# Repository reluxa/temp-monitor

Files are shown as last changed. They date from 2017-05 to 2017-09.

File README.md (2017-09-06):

# temp-monitor
Wifi based temperature monitor based on ESP8266 NodeMCU V3 and high accuracy MCP9808 I2C sensor module.

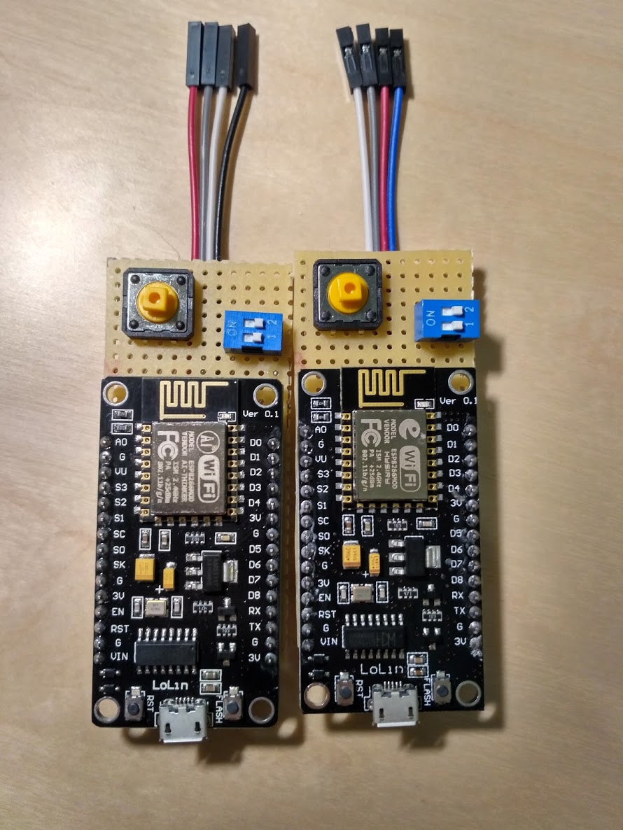
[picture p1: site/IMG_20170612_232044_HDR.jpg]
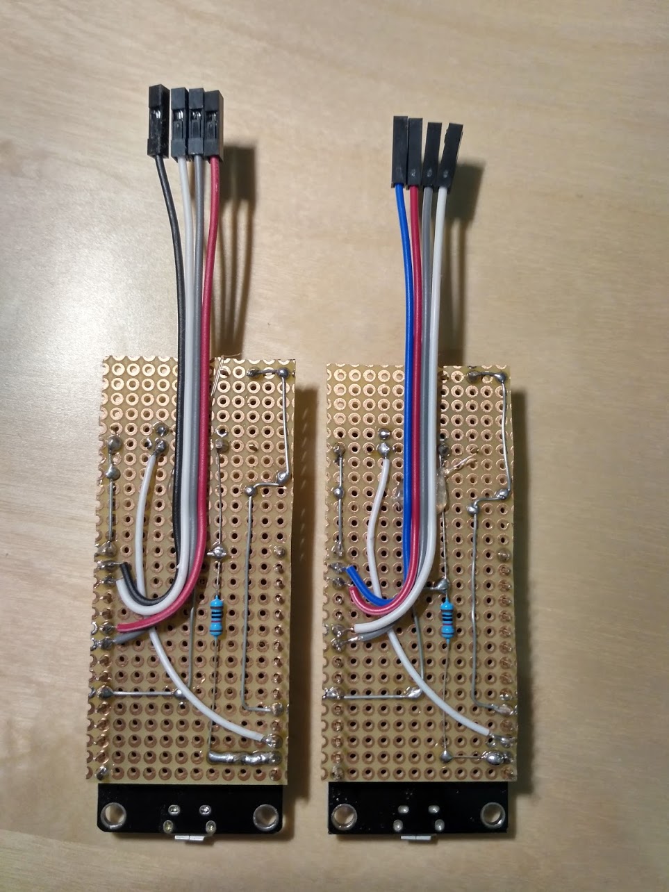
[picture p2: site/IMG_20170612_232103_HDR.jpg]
 

## 3D printed case

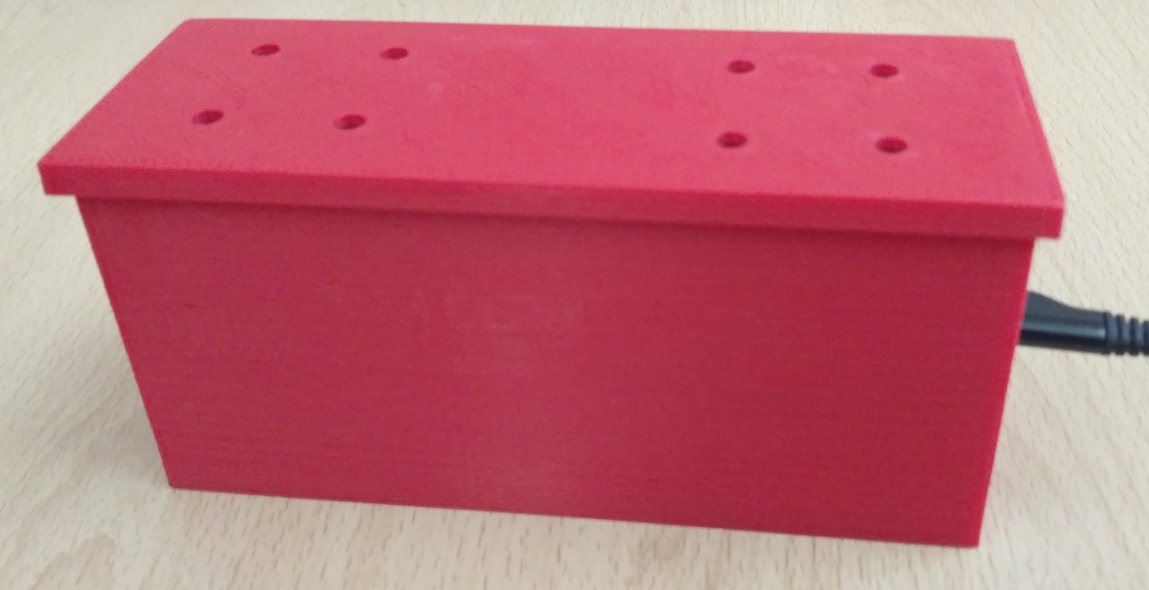
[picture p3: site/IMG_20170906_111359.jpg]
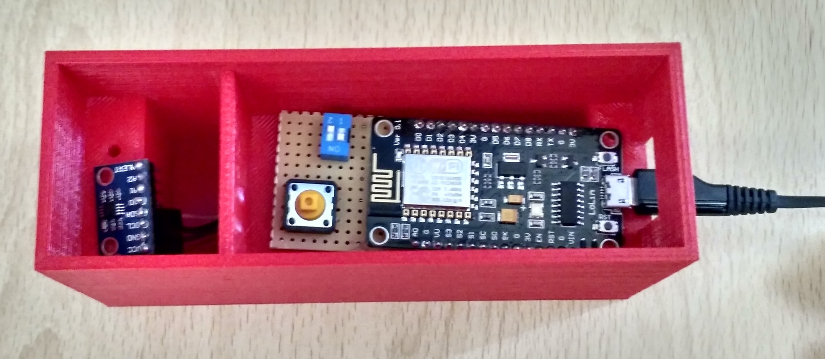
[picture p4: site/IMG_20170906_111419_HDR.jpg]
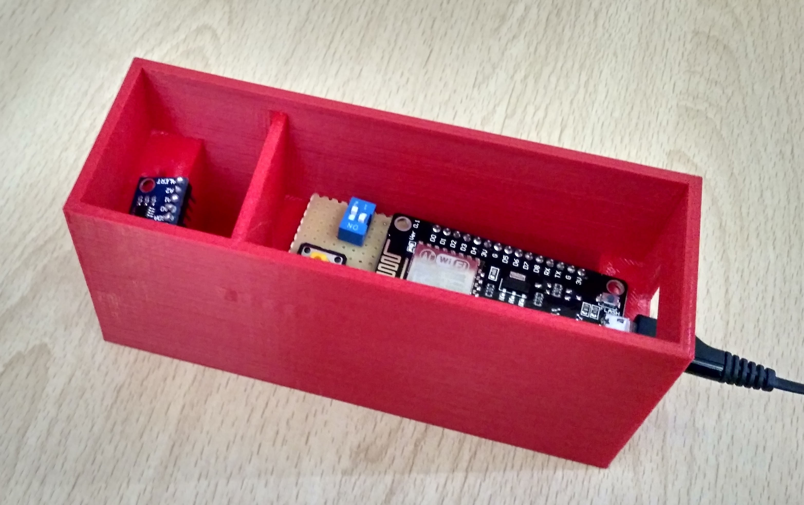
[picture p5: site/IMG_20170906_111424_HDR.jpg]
  

## Features

* The MCP9808 has been selected as the chip accuracy is around 0.25 ℃ in room temp rang. This is much better compared to the other more popular (but also cheaper) sensors (DHT11, DHT22, DS1820B) as they usually have 1 ℃ accuracy without calibration according to their datasheets.
* Uses WIFI manager (https://github.com/tzapu/WiFiManager) to set the configuratio parameters
* The configuration portal can be triggered by pushing the tactile switch while the device is booting up
* The configuration json is saved to the internal SPIFFS, so it's preserved while the device is switched off
* The device goes into deep sleep for 60 seconds after it has finished the read cycle, the dip switch is required here because the reset pin must not be connected to the to the D?? pin while the sketches are uploaded from Arduino IDE 
* Integrated with the company captive portal (once it is connected to the WIFI using the PSK then it also need to be authenticated with and LDAP user/password pair on the captive portal)
* The measured sensor values are sent to blynk using the configured blynk key
* The measured sensor values are sent to the configured MQTT topic ( *topicname* and *topicname/esp chip ip* )
* A software based watchdog has been implemented which resets the ESP if it is running for more than 30 seconds (a usual cycle takes 5-7 seconds)

## Future improvement ideas 
* Implement DNS tunneling to send sensor data embedded in DNS requests instead of MQTT so an open quest wifi can be used wihtout any kind of authentication  
* HTTP Based remote update which is triggerd by an MQTT
* Theare are 1-2 faulty sensor reads per day (above 100C or -0.06C, etc...) this should be filtered out and the measuring should be repeated.

# Bill of Materials

Item | Price | Image | Url
-----|-------|-------------|----
ESP8266 NodeMCU V3| US $2.61 || https://goo.gl/DwVFW4
MCP 9808 I2C High accuracy sensor | US $3.33 |  | https://goo.gl/uG1uYr
5 X 7 cm PCB Board | US $0.33 |  | https://goo.gl/f7Y47i
DIP Switch 1P | US $1.20 (10pcs)|  | https://goo.gl/7sHMXX
Push Button | US $1.45 (20pcs)|  | https://goo.gl/8Kr8Ng
Dupont wires | US $0.31 |  | https://goo.gl/uZkXnA 
10K ohm resistor | US $0.95 |  | https://goo.gl/5iU3pM
Power supply | US $2.36 |  | https://goo.gl/fMZzbB
**In total** | **US $12.21** |

# Blynk based mobile app
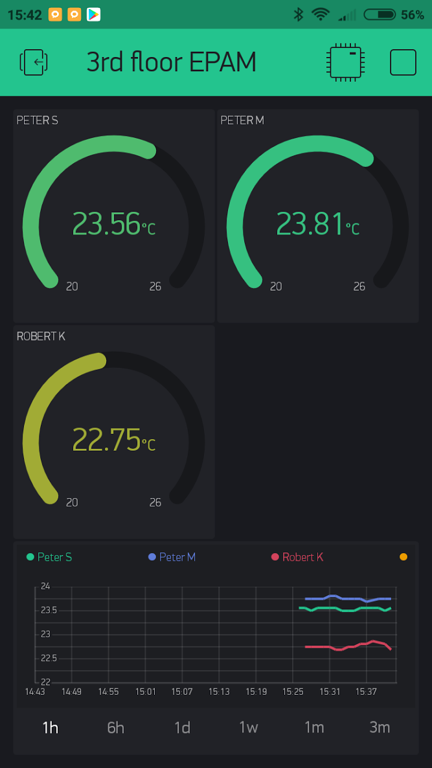
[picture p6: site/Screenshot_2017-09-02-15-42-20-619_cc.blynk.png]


# Live (serverless) heatmap 
https://rawgit.com/reluxa/temp-monitor/master/site/index.html

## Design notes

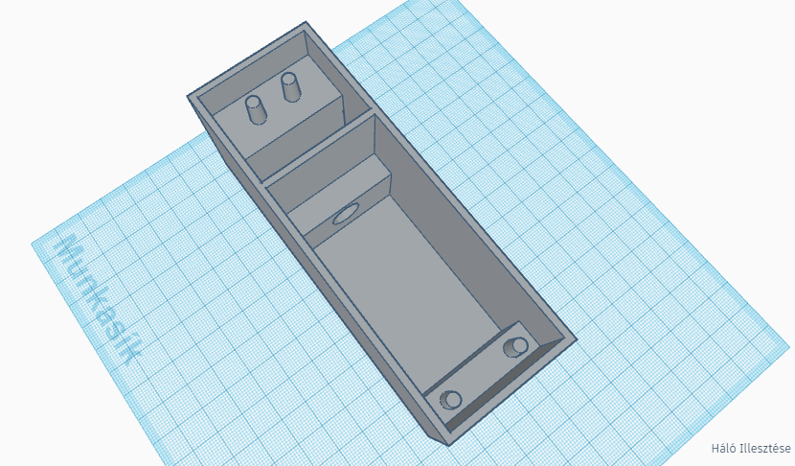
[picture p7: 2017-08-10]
casing/tinkercad/casing_tinkarcad_1.PNG

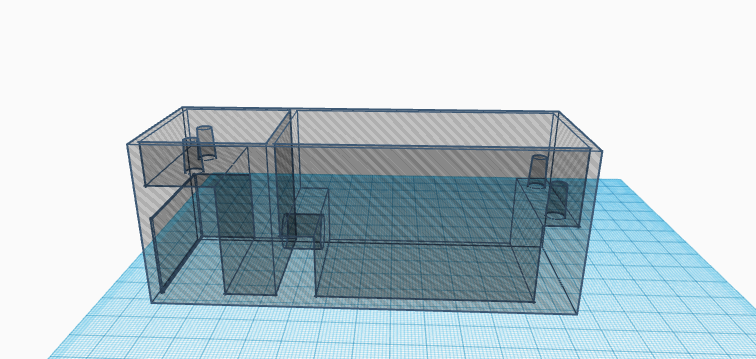
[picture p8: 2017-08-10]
casing/tinkercad/casing_tinkarcad_2.PNG

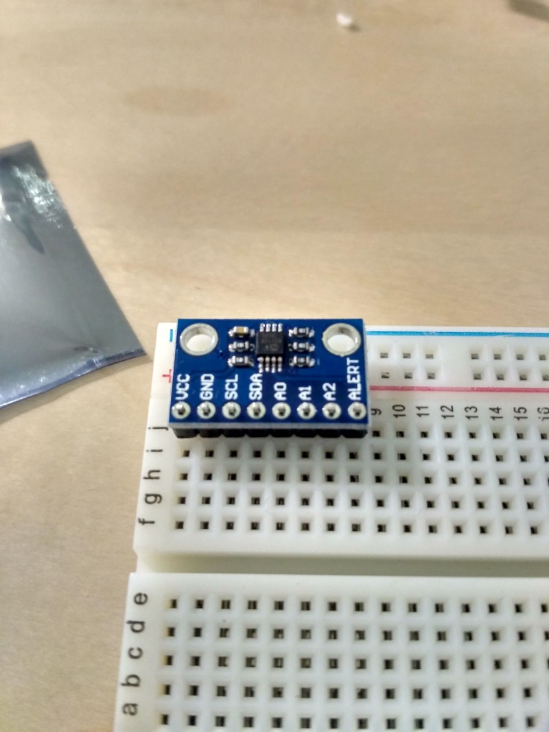
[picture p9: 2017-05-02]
site/IMG_20170501_121737_HDR.jpg

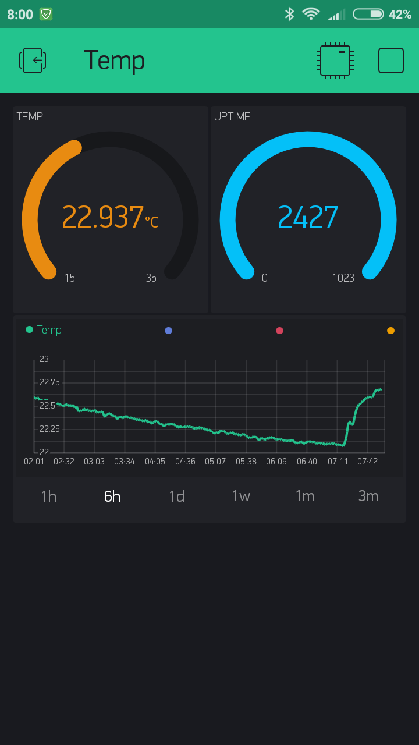
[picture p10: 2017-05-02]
site/Screenshot_2017-05-02-08-00-39-010_cc.blynk.png

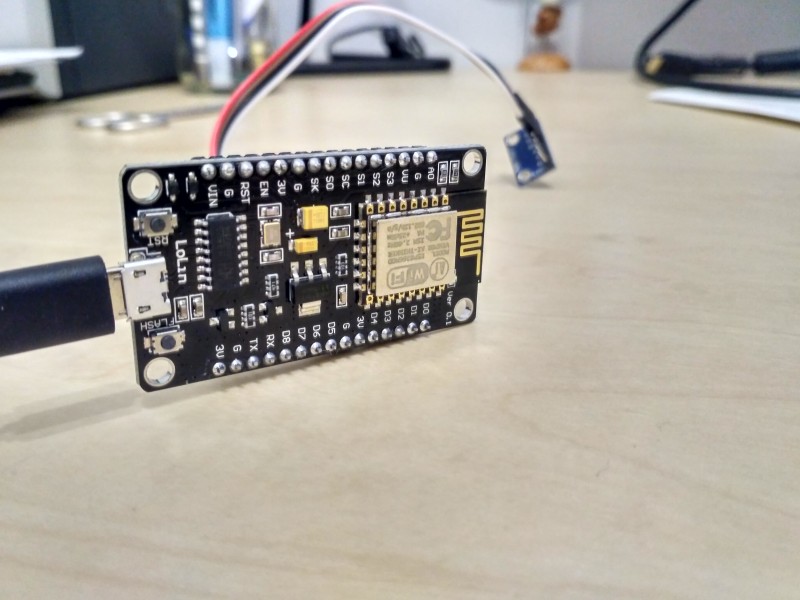
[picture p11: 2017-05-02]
site/IMG_20170502_081327_HDR.jpg

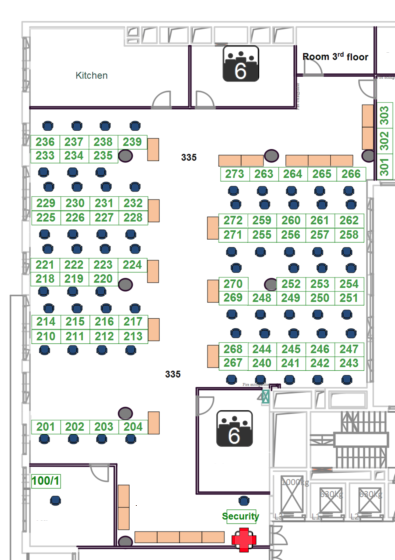
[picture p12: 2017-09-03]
site/3rdfloor.png

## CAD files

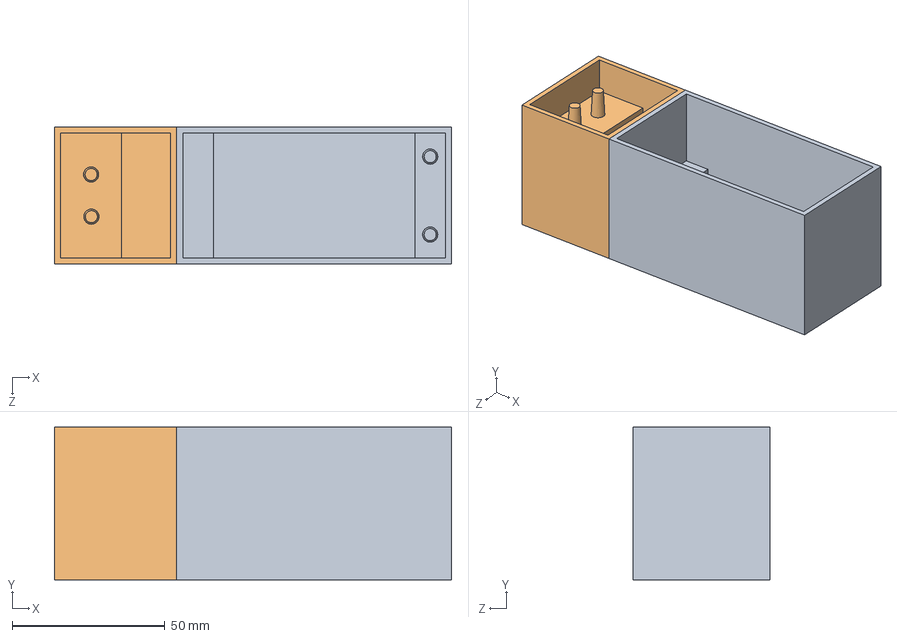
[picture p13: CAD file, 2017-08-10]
casing/solidworks/Assem1.SLDASM
130.0 x 50.0 x 45.0 mm

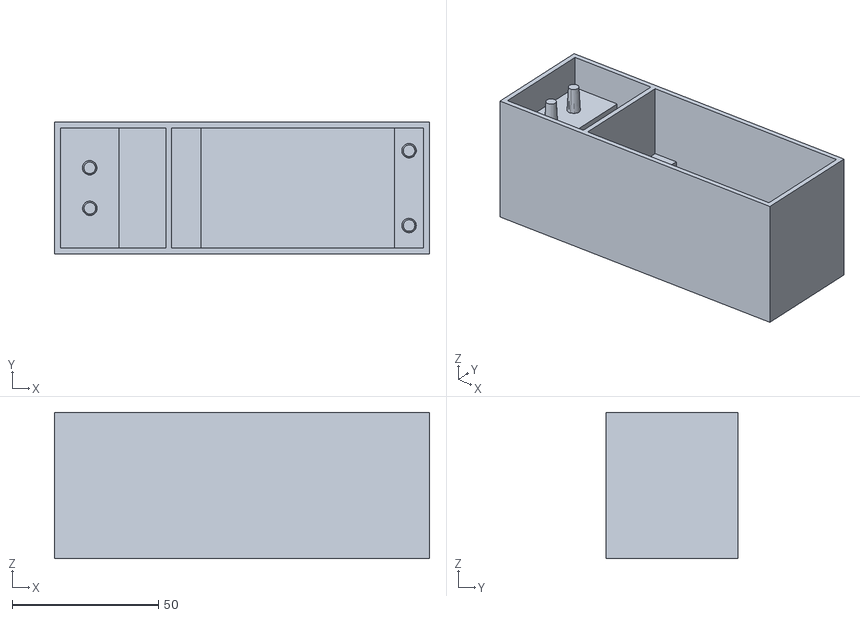
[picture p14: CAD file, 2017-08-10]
casing/tinkercad/Temp project casing.stl
128.0 x 45.0 x 50.0

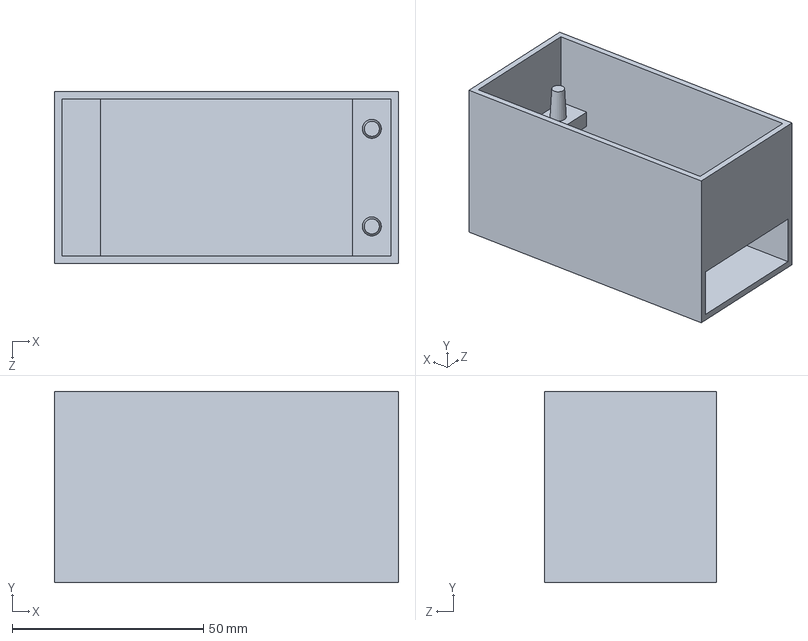
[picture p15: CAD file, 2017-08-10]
casing/solidworks/Part1.SLDPRT
90.0 x 50.0 x 45.0 mm

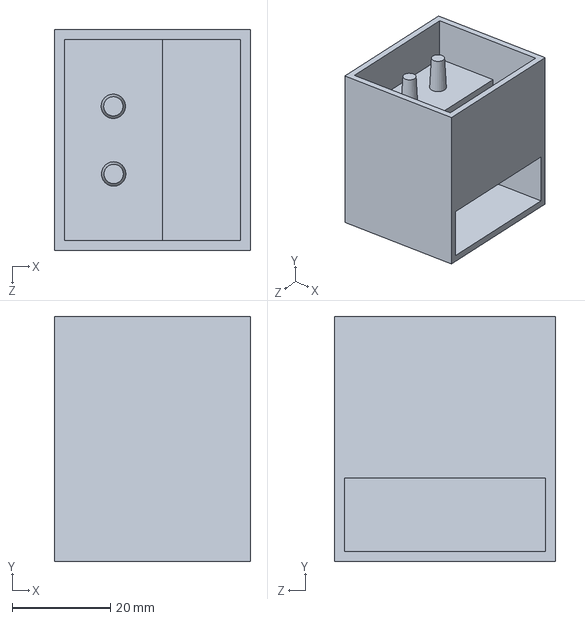
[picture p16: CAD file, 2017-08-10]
casing/solidworks/Part2.SLDPRT
40.0 x 50.0 x 45.0 mm

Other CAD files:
casing/solidworks/Assem1 - Part1-1.STL
casing/solidworks/Assem1 - Part2-1.STL

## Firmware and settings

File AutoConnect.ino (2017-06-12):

#include <FS.h>                   
#include <Wire.h>
#include "Adafruit_MCP9808.h"

#include <ESP8266WiFi.h>          //ESP8266 Core WiFi Library (you most likely already have this in your sketch)
#include <DNSServer.h>            //Local DNS Server used for redirecting all requests to the configuration portal
#include <ESP8266WebServer.h>     //Local WebServer used to serve the configuration portal
#include <WiFiManager.h>          //https://github.com/tzapu/WiFiManager WiFi Configuration Magic
#include <ArduinoJson.h>          

#include <BlynkSimpleEsp8266.h>
#include <PubSubClient.h>

#define TRIGGER_PIN 13 //the pushbutton

Adafruit_MCP9808 tempsensor = Adafruit_MCP9808();

int start = 0;
bool isConfig = false;
bool shouldSaveConfig = false;
float lastTemp = 0.0;

char mqtt_server[40];
char mqtt_port[6] = "8080";
char mqtt_user[40];
char mqtt_password[40];
char mqtt_topic[40];
char blynk_token[34] = "YOUR_BLYNK_TOKEN";
char captive_user[40];
char captive_password[40];

void doMeasurement() {
  while (!tempsensor.begin()) {
    Serial.println("Couldn't find MCP9808!");
    delay(100);
  }
  
  Serial.println("\nwake up MCP9808.... "); 
  tempsensor.wake();   // wake up, ready to read!
  lastTemp = tempsensor.readTempC();
  Serial.print("Temp: "); Serial.print(lastTemp); Serial.println("*C\t"); 
  Serial.println("Shutdown MCP9808.... ");
  tempsensor.shutdown();
}

void sendBlynk() {
  Serial.println("Connecting to Blynk");
  Blynk.config(blynk_token);
  Blynk.connect();
  Serial.println("Sending data to Blynk");
  Blynk.virtualWrite(V5, lastTemp);
}

void sendMqtt() {
  WiFiClient espClient;
  PubSubClient client(espClient);
  client.setServer(mqtt_server, atoi(mqtt_port));
  Serial.print("Attempting MQTT connection...");
  String clientId = "Client-" + String();

  String payload = String(ESP.getChipId());
  payload.concat(" ");
  payload.concat(lastTemp);

  if (client.connect(clientId.c_str(), mqtt_user, mqtt_password)) {
     Serial.println("connected");
     client.publish(mqtt_topic, payload.c_str(), true);
     client.disconnect();
  } else {
     Serial.print("failed, rc=");
     Serial.print(client.state());
  }

}


void reloadConfiguration() {
    Serial.println("mounting FS...");
    if (SPIFFS.begin()) {
      Serial.println("mounted file system...");
      if (SPIFFS.exists("/config.json")) {
        //file exists, reading and loading
        Serial.println("reading config file");
        File configFile = SPIFFS.open("/config.json", "r");
        if (configFile) {
          Serial.println("opened config file");
          size_t size = configFile.size();
          // Allocate a buffer to store contents of the file.
          std::unique_ptr<char[]> buf(new char[size]);
  
          configFile.readBytes(buf.get(), size);
          DynamicJsonBuffer jsonBuffer;
          JsonObject& json = jsonBuffer.parseObject(buf.get());
          //json.printTo(Serial);
          if (json.success()) {
            Serial.println("\nparsed json");
  
            strcpy(mqtt_server, json["mqtt_server"]);
            strcpy(mqtt_port, json["mqtt_port"]);
            strcpy(mqtt_user, json["mqtt_user"]);
            strcpy(mqtt_password, json["mqtt_password"]);
            strcpy(mqtt_topic, json["mqtt_topic"]);            
            strcpy(blynk_token, json["blynk_token"]);
            strcpy(captive_user, json["captive_user"]);            
            strcpy(captive_password, json["captive_password"]);
          } else {
            Serial.println("failed to load json config");
          }
        }
      } else {
        Serial.println("Config file does not exist.");
      }
    } else {
      Serial.println("failed to mount FS");
    }
}


void establishWiFi() {
  WiFiManager wifiManager;
  wifiManager.setDebugOutput(false);
  wifiManager.setConfigPortalTimeout(180);
  wifiManager.autoConnect();
  Serial.println("connected...yeey :)");
}

void saveConfigCallback () {
  Serial.println("Should save config");
  shouldSaveConfig = true;
}

void configPortal() {
    WiFiManagerParameter custom_mqtt_server("server", "mqtt server", mqtt_server, 40);
    WiFiManagerParameter custom_mqtt_port("port", "mqtt port", mqtt_port, 6);
    WiFiManagerParameter custom_mqtt_user("user", "mqtt user", mqtt_user, 40);
    WiFiManagerParameter custom_mqtt_password("password", "mqtt password", mqtt_password, 40);
    WiFiManagerParameter custom_mqtt_topic("topic", "mqtt topic", mqtt_topic, 40);
    WiFiManagerParameter custom_blynk_token("blynk", "blynk token", blynk_token, 34);
    WiFiManagerParameter custom_captive_user("captiveuser", "captive user", captive_user, 40);
    WiFiManagerParameter custom_captive_password("captivepassword", "captive password", captive_password, 40);

   
    WiFiManager wifiManager;
    wifiManager.setSaveConfigCallback(saveConfigCallback);
    wifiManager.addParameter(&custom_mqtt_server);
    wifiManager.addParameter(&custom_mqtt_port);
    wifiManager.addParameter(&custom_mqtt_user);
    wifiManager.addParameter(&custom_mqtt_password);
    wifiManager.addParameter(&custom_mqtt_topic);
    wifiManager.addParameter(&custom_blynk_token);
    wifiManager.addParameter(&custom_captive_user);
    wifiManager.addParameter(&custom_captive_password);


    String ssid = "ESP" + String(ESP.getChipId());

    if (!wifiManager.startConfigPortal(ssid.c_str())) {
      Serial.println("failed to connect and hit timeout");
      delay(3000);
      //reset and try again, or maybe put it to deep sleep
      ESP.reset();
      delay(5000);
    }
    Serial.println("connected...yeey :)");

    strcpy(mqtt_server, custom_mqtt_server.getValue());
    strcpy(mqtt_port, custom_mqtt_port.getValue());
    strcpy(mqtt_user, custom_mqtt_user.getValue());
    strcpy(mqtt_password, custom_mqtt_password.getValue());
    strcpy(mqtt_topic, custom_mqtt_topic.getValue());
    strcpy(blynk_token, custom_blynk_token.getValue());
    strcpy(captive_user, custom_captive_user.getValue());
    strcpy(captive_password, custom_captive_password.getValue());

    

  //save the custom parameters to FS
  if (shouldSaveConfig) {
    Serial.println("saving config");
    DynamicJsonBuffer jsonBuffer;
    JsonObject& json = jsonBuffer.createObject();
    json["mqtt_server"] = mqtt_server;
    json["mqtt_port"] = mqtt_port;
    json["mqtt_user"] = mqtt_user;
    json["mqtt_password"] = mqtt_password;
    json["mqtt_topic"] = mqtt_topic;
    json["blynk_token"] = blynk_token;
    json["captive_user"] = captive_user;
    json["captive_password"] = captive_password;
    
    File configFile = SPIFFS.open("/config.json", "w");
    if (!configFile) {
      Serial.println("failed to open config file for writing");
    }

    json.printTo(Serial);
    json.printTo(configFile);
    configFile.close();
  }
}


String urlencode(String str) {
    String encodedString="";
    char c;
    char code0;
    char code1;
    char code2;
    for (int i =0; i < str.length(); i++){
      c=str.charAt(i);
      if (c == ' '){
        encodedString+= '+';
      } else if (isalnum(c)){
        encodedString+=c;
      } else{
        code1=(c & 0xf)+'0';
        if ((c & 0xf) >9){
            code1=(c & 0xf) - 10 + 'A';
        }
        c=(c>>4)&0xf;
        code0=c+'0';
        if (c > 9){
            code0=c - 10 + 'A';
        }
        code2='\0';
        encodedString+='%';
        encodedString+=code0;
        encodedString+=code1;
        //encodedString+=code2;
      }
      yield();
    }
    return encodedString;
}

void authenticate() {
  WiFiClientSecure client;
  
  while (!client.connect("7.7.7.7", 443)) {
    Serial.println("connection failed");
    delay(500);
  }
  
  String url = "/login.html?redirect=go.microsoft.com/fwlink/?LinkID=219472&clcid=0x409";
  String postParams = "buttonClicked=4&err_flag=0&err_msg=&info_flag=0&info_msg=&redirect_url=http%3A%2F%2Fgo.microsoft.com%2Ffwlink%2F%3FLinkID%3D219472%26clcid%3D0x409&network_name=Guest+Network&username=" +
  urlencode(captive_user) + 
  "&password=" +
  urlencode(captive_password);

  client.print(String("POST ") + url + " HTTP/1.1\r\n" +
               "Host: 7.7.7.7\r\n" +
               "User-Agent: Mozilla/5.0 (Windows NT 10.0; Win64; x64) AppleWebKit/537.36 (KHTML, like Gecko) Chrome/58.0.3029.110 Safari/537.36\r\n" +
               "Content-Type: application/x-www-form-urlencoded\r\n" +
               "Connection: close\r\n"
               "Content-Length: " + postParams.length() + "\r\n\r\n" +
               postParams);

  while (client.connected()) {
    String line = client.readStringUntil('\n');
    //Serial.println(line);
  }
}

bool checkConnection() {
      // Use WiFiClient class to create TCP connections
    WiFiClient clienthttp;

    if (!clienthttp.connect("gstatic.com", 80)) {
        Serial.println("connection to http://gstatic.com failed");
        Serial.println("wait 5 sec...");
        delay(5000);
        return false;
    }

      clienthttp.print(String("GET /generate_204 HTTP/1.1\r\n") +
               "Host: gstatic.com\r\n" +
               "User-Agent: Mozilla/5.0 (Windows NT 10.0; Win64; x64) AppleWebKit/537.36 (KHTML, like Gecko) Chrome/58.0.3029.110 Safari/537.36\r\n" +
               "Connection: close\r\n\r\n");

  Serial.println("request sent to gstatic.com");
  while (clienthttp.connected()) {
    String line = clienthttp.readStringUntil('\n');
    //Serial.println(line);
    if (line.lastIndexOf("204 No Content") != -1) {
      Serial.println("Connected to Internet");
      return true;
    }
  }
  Serial.println("No internet connection is available");
  return false;

}


void timer0_ISR (void) {
  Serial.println("timer0_ISR called. Resetting ESP...");
  ESP.reset();
}

void setup() {
  Serial.begin(115200);

   //SPIFFS.format();
  
  pinMode(TRIGGER_PIN, INPUT);
  start = millis();


  if (digitalRead(TRIGGER_PIN) == HIGH) {
        Serial.println("Starting in configuration mode");
        isConfig = true;
  }

  reloadConfiguration();

  if (!isConfig) {
    noInterrupts();
    timer0_isr_init();
    timer0_attachInterrupt(timer0_ISR);
    timer0_write(ESP.getCycleCount() + 80000000L * 30); // 80MHz * 30 == 30sec
    interrupts();

    establishWiFi();
    if (!checkConnection()) {
      authenticate();
    }
    doMeasurement();
    sendBlynk();
    sendMqtt();
    Serial.printf("Cycle time: %d ms\n", millis() - start);
    Serial.println("Sleeping for 60 sec...");
    ESP.deepSleep(60 * 1000000);
  } else {
    configPortal();
    ESP.restart();
  }
}

void loop() {
  //do nothing in the loop
}

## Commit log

2017-06-29 added casing plans
    [Assem1 - Part1-1.STL, Assem1 - Part2-1.STL, Assem1.SLDASM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]
2017-08-07 moved solidworks stl files and screens into solidworks folder, added tinkercad stl and screen files
    [Assem1 - Part1-1.STL, Assem1 - Part2-1.STL, Temp project casing.stl]
